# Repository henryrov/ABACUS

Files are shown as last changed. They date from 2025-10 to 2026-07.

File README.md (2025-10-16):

What?
=====
ABACUS is a miniature handheld calculator with a slider-based interface, an OLED display, and an integrated LiPo battery that can be charged over USB-C.

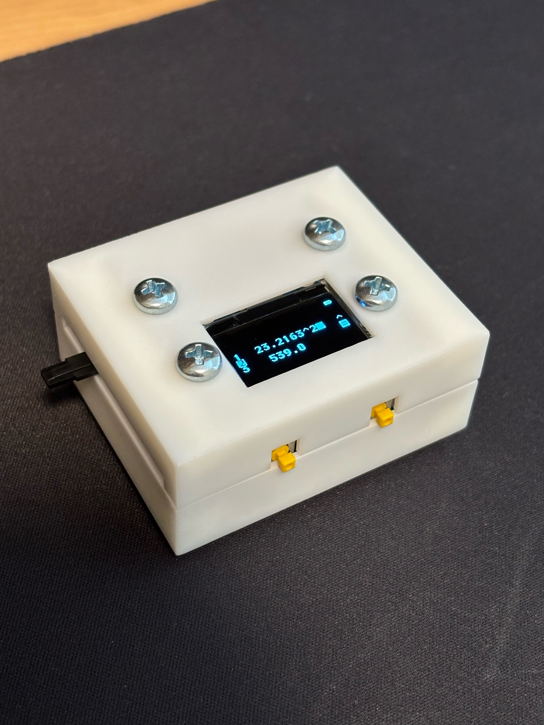
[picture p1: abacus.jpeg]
ABACUS, fully assembled


It is based on the STM32C0, with all software written from scratch (except for picolibc, upon which it depends).

**IMPORTANT**: Many of the characters used for the UI are from the font ChronoType by [Caveras](https://caveras.net). See the FONT_LICENSE file for details on usage. Note that usage of the .raw image files containing these characters, or of the corresponding byte arrays in sprites.c, also falls under the terms of this license, as I understand it.

How?
====
The PCB can be ordered from a commercial manufacturer. Parts were chosen mostly to keep costs down with JLCPCB's assembly service.

The enclosure is designed to be easily 3D printed.

The software can be compiled by running `make` in the abacus_fw directory. This requires picolibc, specifically targeting the Cortex M0. Sprite generation is done using [QSPRITELY](https://github.com/henryrov/QSPRITELY), so be sure to clone with submodules or initialize submodules after cloning. The math itself is done by a modified version of [DESCENT](https://github.com/henryrov/DESCENT).

The board can be flashed over SWD using the 3x1 pin socket on the board (top is SWCLK, middle is SWDIO, bottom is ground). For this, I personally used an FT232H breakout board with openocd, set up similarly to how it is [here](https://github.com/m3y54m/cjmcu-ft232hq-programmer). If using the same setup, simply run `make flash` inside the abacus_fw directory. The debug interface is only available for a few seconds after reset, so either press the reset button or flip the power switch immediately before trying to flash.

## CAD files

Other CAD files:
fusion/battery.f3d
fusion/display_module.f3d
fusion/mounting_tape.f3d

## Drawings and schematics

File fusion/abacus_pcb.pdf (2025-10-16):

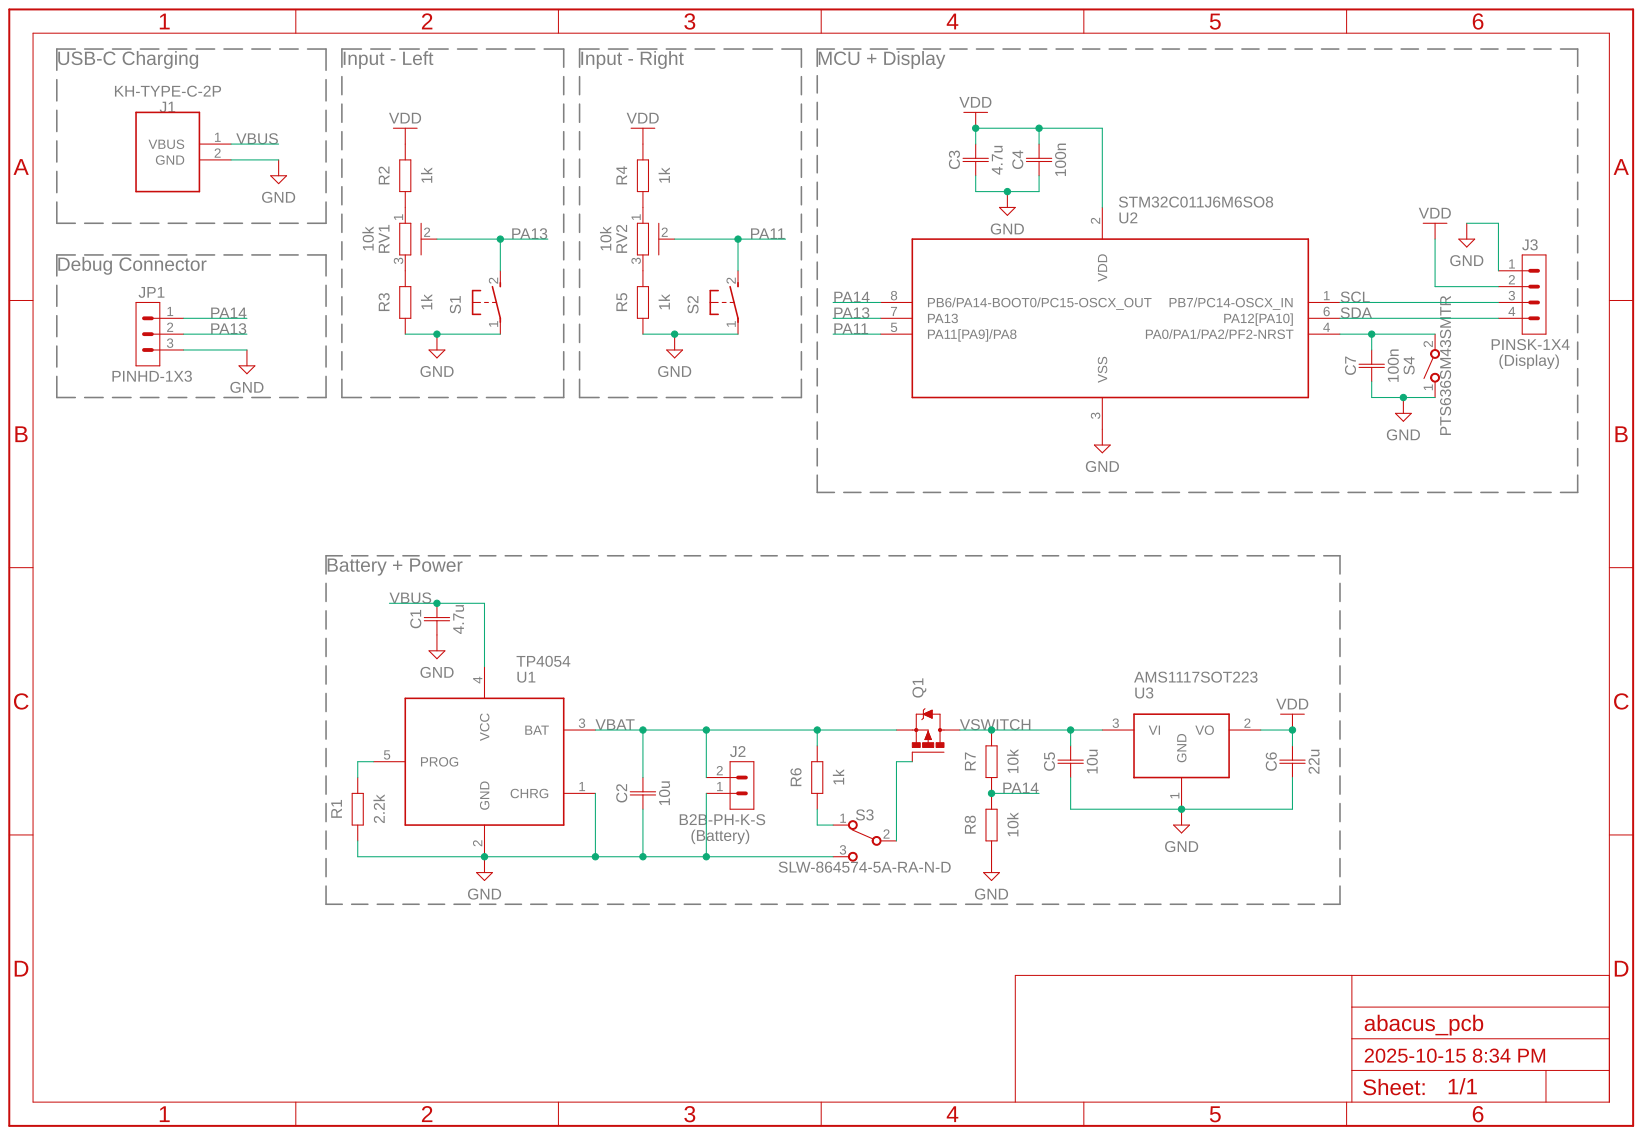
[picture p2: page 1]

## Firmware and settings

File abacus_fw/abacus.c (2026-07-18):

#include <math.h>
#include <stdint.h>
#include <stdbool.h>
#include "abacus.h"
#include "stm32c0.h"
#include "interface.h"
#include "display.h"
#include "battery.h"
#include "sprites/sprites.h"
#include "math/descent.h"

#define enable_interrupts() asm(" cpsie i ")
#define enter_sleep() asm(" wfi ")

#define DISPLAY_ADDR 0x3C
#define ADC_MAX_VAL 4095
#define ADC_BUTTON_THRESHOLD 250
#define ADC_SLIDER_MIN ((ADC_MAX_VAL) * 1000/12000)
#define ADC_SLIDER_MAX ((ADC_MAX_VAL) * 11000/12000)

void default_isr();
void tim14_isr();

enum sprites_e input_string[INPUT_MAX_LENGTH + 1];
bool internal_error = false;
const enum sprites_e sprites_left[] =
{
  SPRITE_0,
  SPRITE_1,
  SPRITE_2,
  SPRITE_3,
  SPRITE_4,
  SPRITE_5,
  SPRITE_6,
  SPRITE_7,
  SPRITE_8,
  SPRITE_9,
  SPRITE_DOT,
  SPRITE_UC_A,
  SPRITE_LC_E,
  SPRITE_LC_PI
};

const uint8_t sprites_left_size = sizeof(sprites_left) / sizeof(enum sprites_e);

const enum sprites_e sprites_right[] =
{
  SPRITE_UC_C,
  SPRITE_UC_D,
  SPRITE_ARROW_LEFT,
  SPRITE_ARROW_RIGHT,
  SPRITE_LEFT_PARENTHESIS,
  SPRITE_RIGHT_PARENTHESIS,
  SPRITE_PLUS,
  SPRITE_MINUS,
  SPRITE_TIMES,
  SPRITE_DIVIDE,
  SPRITE_POWER,
  SPRITE_EQUALS
};

const uint8_t sprites_right_size = sizeof(sprites_right) / sizeof(enum sprites_e);

bool left_button_ready = true;
bool right_button_ready = true;
uint8_t prev_left_selection_i = 0;
uint8_t prev_right_selection_i = 0;
enum sprites_e prev_battery_level = SPRITE_BATTERY_0;
struct ui_state_s ui_state =
{
  .result = 0.0,
  .error_index = -1,
  .sprite_string = input_string,
  .sprite_string_len = 0,
  .sprite_string_i = 0,
  .left_selection_i = 0,
  .right_selection_i = 0,
  .battery_level = SPRITE_BATTERY_0
};


const void *vectors[] __attribute__((section(".init"))) =
{
  default_isr,
  default_isr,
  default_isr,
  default_isr,
  default_isr,
  default_isr,
  default_isr,
  default_isr,
  default_isr,
  default_isr,
  default_isr,
  default_isr,
  default_isr,
  default_isr,
  default_isr,
  default_isr,
  default_isr,
  default_isr,
  default_isr,
  tim14_isr,
};

void sprite_string_try_insert(enum sprites_e sprite)
{
  if (ui_state.sprite_string_i < INPUT_MAX_LENGTH)
    {
      ui_state.sprite_string[ui_state.sprite_string_i] = sprite;

      if (ui_state.sprite_string_i == ui_state.sprite_string_len)
        {
          /* Inserting at the end of the string */

          ui_state.sprite_string_len++;
        }

      ui_state.sprite_string_i++;
    }
}

void sprite_string_delete()
{
  if ((ui_state.sprite_string_i == ui_state.sprite_string_len)
      && (ui_state.sprite_string_i > 0))
    {
      /* Deleting rightmost sprite */

      ui_state.sprite_string_i--;
      ui_state.sprite_string[ui_state.sprite_string_i] = SPRITE_BLANK;
    }
  else
    {
      /* Move everything that comes after back one index */

      for (uint8_t i = ui_state.sprite_string_i;
           ui_state.sprite_string[i] != SPRITE_BLANK;
           i++)
        {
          ui_state.sprite_string[i] = ui_state.sprite_string[i + 1];
        }
    }

  ui_state.sprite_string_len--;
}

void default_isr()
{
  /* This should never run */

  while (1);
}

void tim14_isr()
{
  bool timeout_error = false;
  internal_error = false;

  /* Read ADC to determine selection or button presses */

  WAIT_WITH_TIMEOUT(!(ADC_ISR & 1), DEFAULT_TIMEOUT, timeout_error);
  if (timeout_error)
    {
      internal_error = true;
      TIM14_SR &= ~(1);
      return;
    }

  ADC_CR |= 1 << 2;
  WAIT_WITH_TIMEOUT(!(ADC_ISR & (1 << 2)), DEFAULT_TIMEOUT, timeout_error);
  if (timeout_error)
    {
      internal_error = true;
      TIM14_SR &= ~(1);
      return;
    }

  uint16_t adc_vrefint = ADC_DR;
  ADC_CR |= 1 << 2;
  WAIT_WITH_TIMEOUT(!(ADC_ISR & (1 << 2)), DEFAULT_TIMEOUT, timeout_error);
  if (timeout_error)
    {
      internal_error = true;
      TIM14_SR &= ~(1);
      return;
    }

  uint16_t adc_right = ADC_DR;
  ADC_CR |= 1 << 2;
  WAIT_WITH_TIMEOUT(!(ADC_ISR & (1 << 2)), DEFAULT_TIMEOUT, timeout_error);
  if (timeout_error)
    {
      internal_error = true;
      TIM14_SR &= ~(1);
      return;
    }

  uint16_t adc_left = ADC_DR;
  ADC_CR |= 1 << 2;
  WAIT_WITH_TIMEOUT(!(ADC_ISR & (1 << 2)), DEFAULT_TIMEOUT, timeout_error);
  if (timeout_error)
    {
      internal_error = true;
      TIM14_SR &= ~(1);
      return;
    }

  uint16_t adc_bat = ADC_DR;
  float supply_voltage = 3.0 * VREFINT_3V / adc_vrefint;
  float battery_voltage = 2 * (supply_voltage * adc_bat) / ADC_MAX_VAL;
  enum sprites_e new_battery_level = get_battery_level(battery_voltage);
  if (new_battery_level != prev_battery_level)
    {
      ui_state.battery_level = new_battery_level;
      interface_draw_battery();
      prev_battery_level = new_battery_level;
    }

  bool input_changed = false;

  if ((adc_right <= ADC_BUTTON_THRESHOLD) && right_button_ready)
    {
      /* Right button pressed */

      switch (sprites_right[ui_state.right_selection_i])
        {
        case SPRITE_EQUALS:
          int8_t error = -1;
          float result = evaluate_expression_from_sprites(ui_state.sprite_string,
                                                          &error);
          ui_state.error_index = error;
          input_changed = true;
          if (error < 0)
            {
              ui_state.result = result;
              interface_draw_result();
            }
          break;

        case SPRITE_UC_C:
          /* Clear input string */

          ui_state.sprite_string_i = 0;
          ui_state.sprite_string_len = 0;
          input_changed = true;
          for (int i = 0; i <= INPUT_MAX_LENGTH; i++)
            {
              input_string[i] = SPRITE_BLANK;
            }
          break;

        case SPRITE_UC_D:
          sprite_string_delete();
          input_changed = true;
          break;

        case SPRITE_ARROW_LEFT:
          if (ui_state.sprite_string_i > 0)
            {
              ui_state.sprite_string_i--;
              input_changed = true;
            }
          break;

        case SPRITE_ARROW_RIGHT:
          if (ui_state.sprite_string_i < ui_state.sprite_string_len)
            {
              ui_state.sprite_string_i++;
              input_changed = true;
            }
          break;

        default:
          sprite_string_try_insert(sprites_right[ui_state.right_selection_i]);
          input_changed = true;
          break;
        }

      right_button_ready = false;
    }
  else if (adc_right > ADC_BUTTON_THRESHOLD)
    {
      uint16_t selection_separation = (ADC_SLIDER_MAX - ADC_SLIDER_MIN)
        / sprites_right_size;
      ui_state.right_selection_i = sprites_right_size - 1
        - (uint8_t)((adc_right - ADC_SLIDER_MIN) / selection_separation);
      if (ui_state.right_selection_i >= sprites_right_size)
        {
          ui_state.right_selection_i = sprites_right_size - 1;
        }
      else if (ui_state.right_selection_i < 0)
        {
          ui_state.right_selection_i = 0;
        }

      right_button_ready = true;
    }

  if ((adc_left <= ADC_BUTTON_THRESHOLD) && left_button_ready)
    {
      /* Left button pressed */

      sprite_string_try_insert(sprites_left[ui_state.left_selection_i]);
      input_changed = true;

      left_button_ready = false;
    }
  else if (adc_left > ADC_BUTTON_THRESHOLD)
    {
      uint16_t selection_separation = (ADC_SLIDER_MAX - ADC_SLIDER_MIN)
        / sprites_left_size;
      ui_state.left_selection_i = sprites_left_size - 1
        - (uint8_t)((adc_left - ADC_SLIDER_MIN) / selection_separation);
      if (ui_state.left_selection_i >= sprites_left_size)
        {
          ui_state.left_selection_i = sprites_left_size - 1;
        }
      else if (ui_state.left_selection_i < 0)
        {
          ui_state.left_selection_i = 0;
        }

      left_button_ready = true;
    }

  if (input_changed)
    {
      interface_draw_input();
    }

  if (ui_state.right_selection_i != prev_right_selection_i)
    {
      interface_draw_selection(SIDE_RIGHT);
      prev_right_selection_i = ui_state.right_selection_i;
    }

  if (ui_state.left_selection_i != prev_left_selection_i)
    {
      interface_draw_selection(SIDE_LEFT);
      prev_left_selection_i = ui_state.left_selection_i;
    }

  interface_draw_error();

  TIM14_SR &= ~(1);
}

void init()
{
  /* Peripheral clock setup */

  RCC_IOPENR = 0b11;
  RCC_APBENR1 = 1 << 21;
  RCC_APBENR2 = (1 << 15) | (1 << 20) | 1;

  /* Delay to make sure clocks are active and the display is powered,
   * and to allow debugging.
   */

  for (int i = 0; i < 2000000; i++)
    {
      /* Mark i as used to stop this from being optimized out */

      __asm__ volatile("" : "+g" (i));
    }

  /* Remap PA12 to PA10 */

  SYSCFG_CFGR3 |= 1 << 8;
  SYSCFG_CFGR1 |= 1 << 4;

  /* ADC setup - calibration then initialization */

  ADC_SMPR |= 0b111;
  ADC_CCR |= 1 << 22;
  ADC_CR |= 1 << 28;
  for (int i = 0; i < 100000; i++);
  ADC_CR |= 1 << 31;
  while (ADC_CR & (1 << 31));
  uint8_t calibration_factor = (ADC_DR & (0x7f)) + 1;

  ADC_CHSELR = (1 << 14) | (1 << 13) | (1 << 11) | (1 << 10);
  ADC_CFGR1 = 1 << 16;
  ADC_CR |= 1;
  while (!(ADC_ISR & 1));
  ADC_CALFACT = calibration_factor;

  /* GPIO pin setup */

  GPIOX_MODER('A') = 0xFFEFFFFF;
  GPIOX_AFRH('A') = 0x00000600;
  GPIOX_MODER('B') = 0xFFFFBFFF;
  GPIOX_AFRL('B') = 0xE0000000;
  GPIOX_OTYPER('A') |= 1 << 10;
  GPIOX_OTYPER('B') |= 1 << 7;
  GPIOX_PUPDR('A') &= ~(0b11 << 26) & ~(0b11 << 28);
  GPIOX_PUPDR('A') |= 0b01 << 20;
  GPIOX_PUPDR('B') |= 0b01 << 14;

  /* I2C setup */

  I2C1_TIMINGR = (10) | (10 << 8) | (1 << 16) | (3 << 20);
  I2C1_CR1 |= 1;
  while (!(I2C1_CR1 & 1));
  I2C1_CR2 = (DISPLAY_ADDR << 1) | (1 << 25);

  display_setup();

  /* Timer setup */

  TIM14_PSC = 11999;
  TIM14_ARR = 39;
  TIM14_DIER |= 1;
  TIM14_CR1 = 1;

  enable_interrupts();
  NVIC_ISER = 1 << 19;

  /* Clear input string */

  for (int i = 0; i <= INPUT_MAX_LENGTH; i++)
    {
      input_string[i] = SPRITE_BLANK;
    }
}

void main()
{
  init();
  interface_draw_input();
  interface_draw_selection(SIDE_LEFT);
  interface_draw_selection(SIDE_RIGHT);
  interface_draw_battery();

  /* Configure sleep on ISR exit */

  SCR |= 1 << 1;

  while (1)
    {
      /* This shouldn't be needed, but it's here just in case */

      enter_sleep();
    }
}

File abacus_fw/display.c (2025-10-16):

#include <stdbool.h>
#include "abacus.h"
#include "display.h"
#include "stm32c0.h"
#include "sprites/sprites.h"

#define DISPLAY_ON 0xAF
#define DISPLAY_SET_COLUMN_LN 0x00
#define DISPLAY_SET_COLUMN_UN 0x10
#define DISPLAY_SET_PAGE 0xB0

enum transfer_type_e
{
  TRANSFER_COMMAND,
  TRANSFER_DATA,
  TRANSFER_RAW
};

void i2c_write(enum transfer_type_e type,
               const uint8_t *bytes,
               uint8_t n_bytes,
               bool invert)
{
  bool timeout_error = false;

  WAIT_WITH_TIMEOUT(I2C1_ISR & (1 << 15), DEFAULT_TIMEOUT, timeout_error);
  if (timeout_error)
    {
      internal_error = true;
      return;
    }

  I2C1_CR2 &= ~(0xff << 16);
  if (type == TRANSFER_RAW)
    {
      I2C1_CR2 |= n_bytes << 16;
    }
  else
    {
      I2C1_CR2 |= (n_bytes + 1) << 16;
    }

  I2C1_CR2 |= 1 << 13;

  WAIT_WITH_TIMEOUT(!(I2C1_ISR & (1 << 1)), DEFAULT_TIMEOUT, timeout_error);
  if (timeout_error)
    {
      internal_error = true;
      return;
    }

  if (type == TRANSFER_COMMAND)
    {
      I2C1_TXDR = 0x00;
    }
  else if (type == TRANSFER_DATA)
    {
      I2C1_TXDR = 0x40;
    }

  for (uint8_t i = 0; i < n_bytes; i++)
    {
      WAIT_WITH_TIMEOUT(!(I2C1_ISR & (1 << 1)), DEFAULT_TIMEOUT, timeout_error);
      if (timeout_error)
        {
          internal_error = true;
          return;
        }

      if (invert)
        {
          I2C1_TXDR = ~bytes[i];
        }
      else
        {
          I2C1_TXDR = bytes[i];
        }
    }
}

void display_setup()
{
  uint8_t bytes[3];
  bytes[0] = 0x8D;
  bytes[1] = 0x14;
  bytes[2] = DISPLAY_ON;
  i2c_write(TRANSFER_COMMAND, bytes, 3, false);

  /* Clear display RAM */

  for (uint8_t page = 0; page < 8; page++)
    {
      display_move(0, page);
      for (uint8_t column = 0; column < 128; column = column + 8)
        {
          display_draw_sprite(SPRITE_BLANK, false);
        }
    }

  display_move(0, 0);
}

void display_move(uint8_t column, uint8_t page)
{
  uint8_t bytes[1];
  bytes[0] = DISPLAY_SET_COLUMN_LN + (column & 0x0F);
  i2c_write(TRANSFER_COMMAND, bytes, 1, false);
  bytes[0] = DISPLAY_SET_COLUMN_UN + ((column >> 4) & 0x0F);
  i2c_write(TRANSFER_COMMAND, bytes, 1, false);
  bytes[0] = DISPLAY_SET_PAGE + page;
  i2c_write(TRANSFER_COMMAND, bytes, 1, false);
}

void display_draw_sprite(enum sprites_e sprite, bool invert)
{
  i2c_write(TRANSFER_DATA, sprites[(uint8_t)sprite], 8, invert);
}

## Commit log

2025-10-16 Public release
    [battery.f3d, display_module.f3d, ft232h_ocd.cfg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]
2026-01-04 Improve battery meter accuracy.
    Battery measurements previously assumed supply voltage of 3.3 V. Now assuming 3 V, which is more accurate.
    [ft232h_ocd.cfg]
2026-02-14 Use internal reference voltage to measure the battery voltage accurately
2026-07-18 Fix compiling with higher optimization levels and lower refresh rate
    [abacus.c]
